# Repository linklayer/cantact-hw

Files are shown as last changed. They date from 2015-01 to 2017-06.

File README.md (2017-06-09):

# CANtact Hardware

This repository contains the hardware design files for the CANtact tool. They 
can be opened and edited with [KiCad](http://www.kicad-pcb.org/).

Documentation can be found on the [Linklayer Wiki](https://wiki.linklayer.com/index.php/CANtact).

A PDF of the schematic is available
[here](https://github.com/CANtact/cantact-hw/blob/master/cantact.pdf?raw=true).

## Official Retailers

- [Linklayer Store](https://store.linklayer.com) (USA)
- [Hacker Warehouse](https://hackerwarehouse.com) (USA)
- [VETEC](http://vctec.co.kr) (South Korea)

## License

Hardware files released under the [Creative Commons Attribution-ShareAlike 4.0
International License](http://creativecommons.org/licenses/by-sa/4.0/) (CC BY-SA
4.0)

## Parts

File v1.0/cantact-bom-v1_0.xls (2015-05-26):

CANtact Bill of Materials |  |  | HW Version: | 1.0
Item | Qty | Reference(s) | Value | MPN | Manufacturer | Package | Digikey P/N
1 | 7 | C1, C11, C13, C16, C2, C4, C6 | 0.1uF | GRM188R71C104KA01D | Murata | 0603 | 490-1532-1-ND
2 | 3 | C10, C14, C15 | 1uF | GRM188R61E105KA12D | Murata | 0603 | 490-3897-1-ND
3 | 3 | C12, C3, C7 | 4.7uF | GRM188R60J475KE19D | Murata | 0603 | 490-3297-1-ND
4 | 2 | C5, C9 | 18pF | CL10C180JB8NNNC | Samsung | 0603 | 1276-1089-1-ND
5 | 1 | C8 | 10nF | GRM188R71H103KA01D | Murata | 0603 | 490-1512-1-ND
6 | 1 | D1 | LED-GREEN | LTST-C191KGKT | Lite-On | 0603 | 160-1446-1-ND
7 | 1 | D2 | LED-RED | LTST-C191KRKT | Lite-On | 0603 | 160-1447-1-ND
9 | 4 | JP2, JP3, JP4, JP5 | 2x2 Header | 15912040 | Molex | 2x2SMD | WM9514-ND
13 | 1 | P1 | USB | USB-B1HSB6 | OST | 4 pin TH | ED2983-ND
15 | 1 | P3 | DB9 | SDS107-PRW1-M09-SN63-11 | Sullins | 9 pin TH | S9575-ND
16 | 1 | R1 | 510 | MCR03ERTF5100 | Rohm | 0603 | RHM510CFCT-ND
17 | 3 | R2, R3, R4 | 120 | MCR03ERTF1200 | Rohm | 0603 | RHM120CFCT-ND
18 | 1 | U1 | STM32F042C6T6 | STM32F042C6T6 | STM | 48 LQFP | 497-14648-ND
19 | 1 | U2 | AAT3221 | AAT3221IGV-3.3-T1 | Skyworks | SOT23-5 | 863-1491-1-ND
20 | 1 | U3 | MCP2561-E/SN | MCP2561-E/SN | Microchip | 8 SOIC | MCP2561-E/SN-ND
21 | 1 | X1 | 16 MHz | 9C-16.000MAAJ-T | TXC | HC49/US | 887-1059-1-ND
22 | 4 | JP2, JP3, J4, JP5 | JUMPER | QPC02SXGN-RC | Sullins | JUMPER | S9337-ND
Total | 36

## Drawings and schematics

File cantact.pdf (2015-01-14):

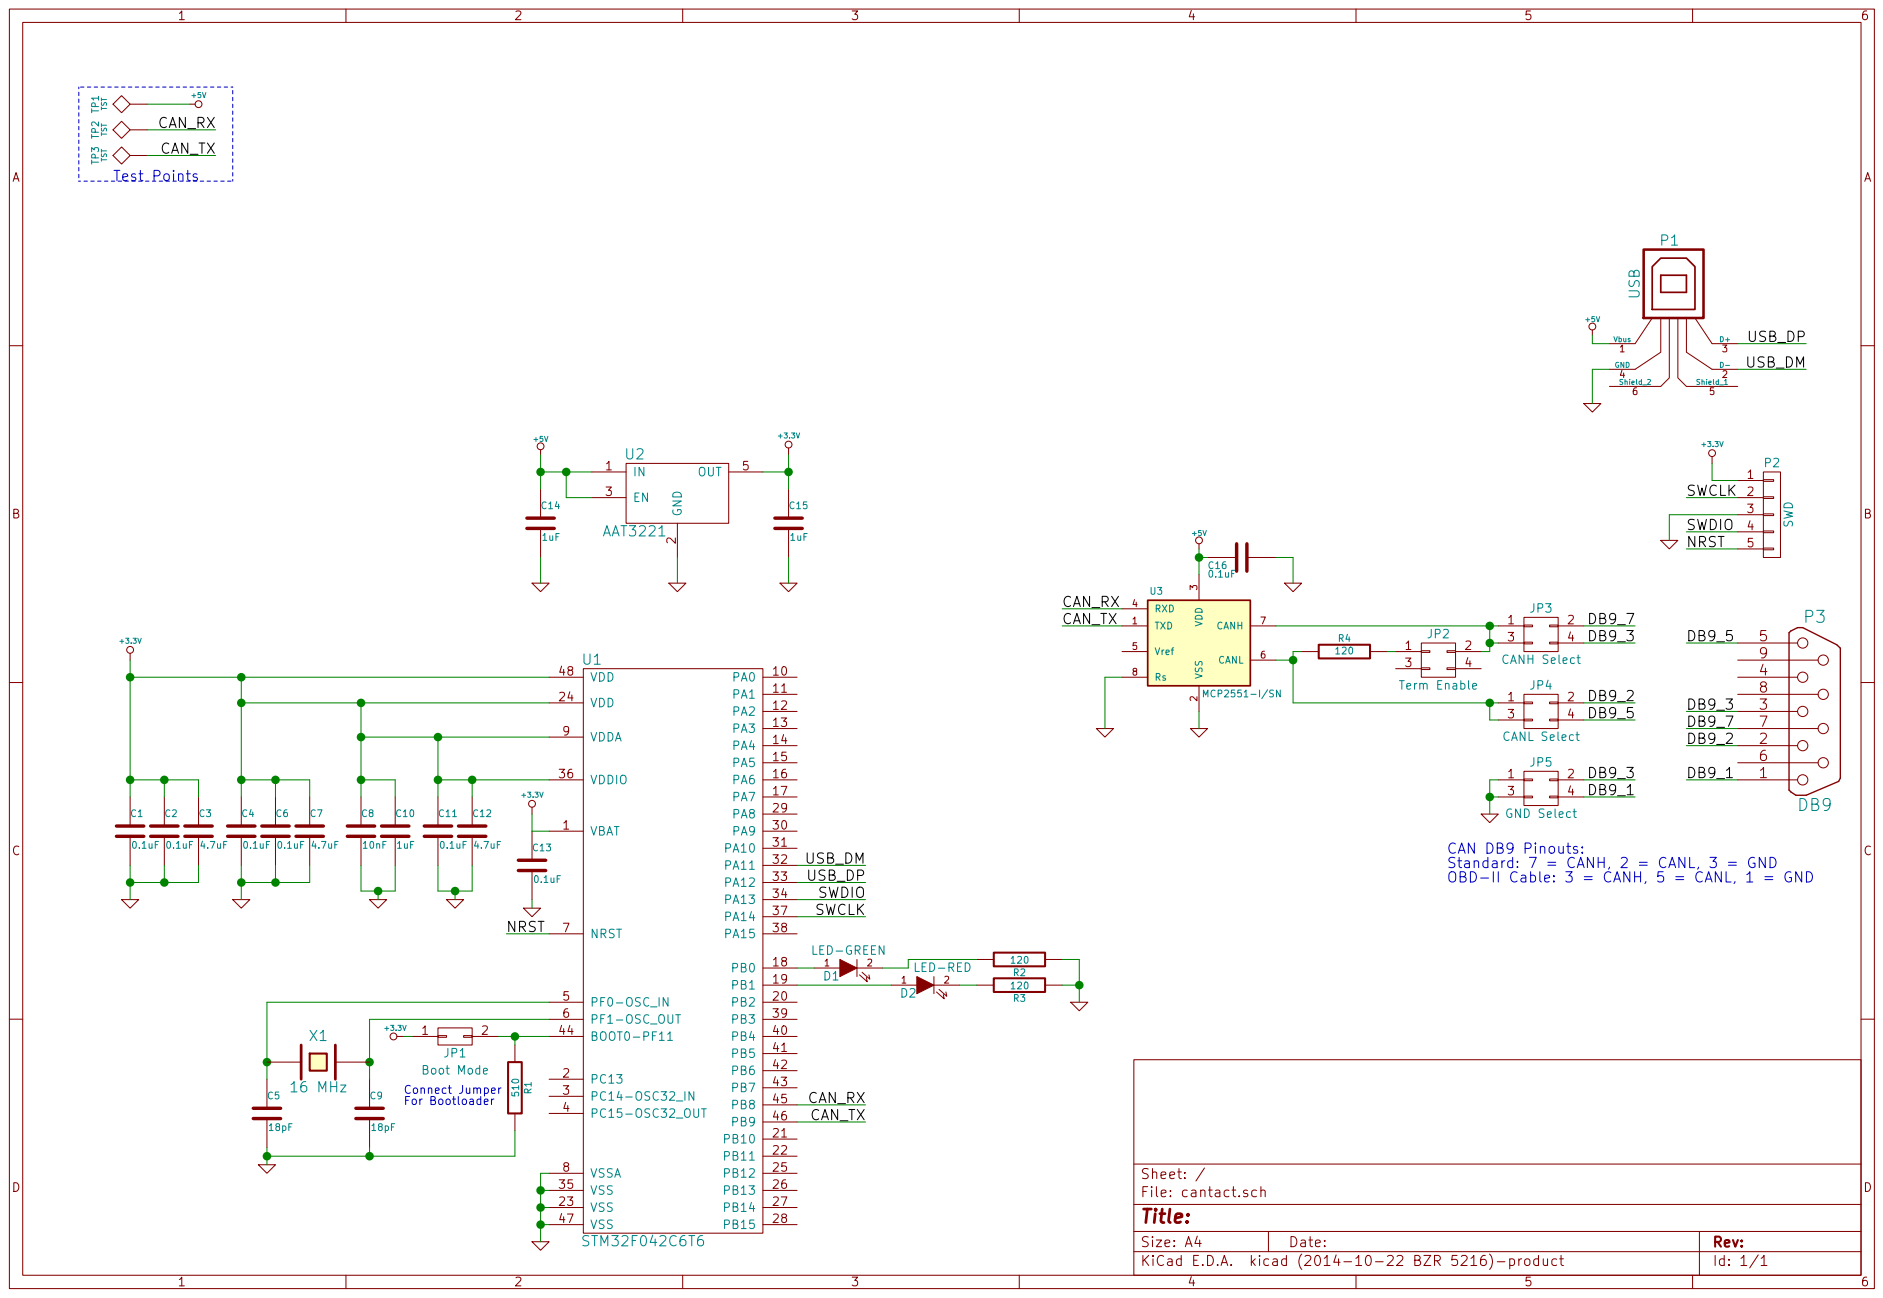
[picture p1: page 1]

3 RXD 4 Vref 5 CANL 6 CANH 7 Rs 8 U3 MCP2551-I/SN CAN_RX
CAN_TX

Id: 1/1 Title: File: cantact.sch Sheet: / C12

Standard: 7 = CANH, 2 = CANL, 3 = GND

OBD-II Cable: 3 = CANH, 5 = CANL, 1 = GND 510 R1

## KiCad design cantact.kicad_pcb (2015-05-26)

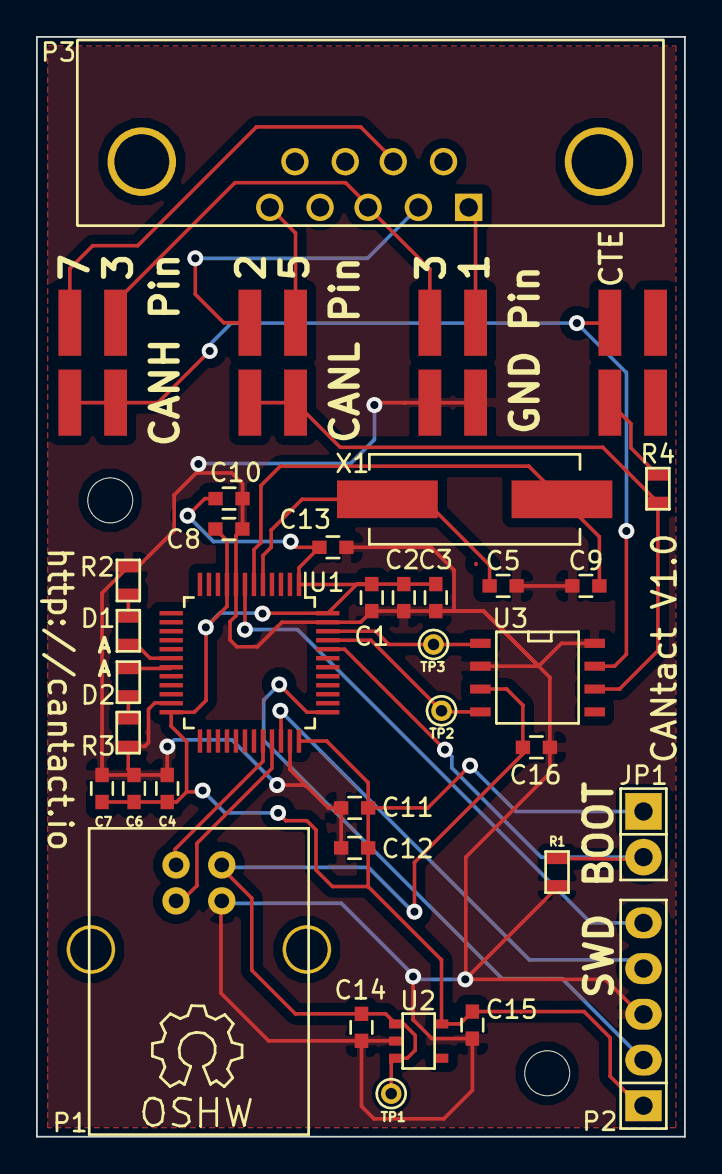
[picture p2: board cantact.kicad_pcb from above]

Board: 2 copper layers, 36.0 x 61.1 mm, 38 parts (0 on the bottom side), 25 nets.

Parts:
C1, C2, C4, C6, C11, C13, C16: 0.1uF; C_0603
C3, C7, C12: 4.7uF; C_0603
C5, C9: 18pF; C_0603
C8: 10nF; C_0603
C10, C14, C15: 1uF; C_0603
D1, D2: LED; SMD-0603
JP1: Boot Mode; Pin_Header_Straight_1x02
JP2: Term Enable; 0015912040
JP3: CANH Select; 0015912040
JP4: CANL Select; 0015912040
JP5: GND Select; 0015912040
P1: USB; USB_B
P2: SWD; Pin_Header_Straight_1x05
P3: DB9; DB9MC
R1: 510; SMD-0603
R2, R3: R; SMD-0603
R4: 120; SMD-0603
SYM: Symbol_OSHW-Logo_SilkScreen_07Jul2012; Symbol_OSHW-Logo_SilkScreen
TP1, TP2, TP3: TST; PINTST
U1: STM32F042C6T6; LQFP-48_7x7mm_Pitch0.5mm
U2: AAT3221; SOT-23-5
U3: MCP2551-I/SN; SOIC-8-N
X1: 16 MHz; Crystal_HC49-SD_SMD

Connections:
+3.3V: C1.1, C2.1, C3.1, C4.1, C6.1, C7.1, C8.1, C10.1, C11.1, C12.1, C13.1, C15.1, JP1.1, P2.1, U1.1, U1.9, U1.24, U1.36, U1.48, U2.5
+5V: C14.1, C16.2, P1.1, TP1.1, U2.1, U2.3, U3.3
/CAN_RX: TP2.1, U1.45, U3.4
/CAN_TX: TP3.1, U1.46, U3.1
/DB9_1: JP5.4, P3.1
/DB9_2: JP4.2, P3.2
/DB9_3: JP3.4, JP5.2, P3.3
/DB9_5: JP4.4, P3.5
/DB9_7: JP3.2, P3.7
/NRST: P2.5, U1.7
/SWCLK: P2.2, U1.37
/SWDIO: P2.4, U1.34
/USB_DM: P1.2, U1.32
/USB_DP: P1.3, U1.33
GND: C1.2, C2.2, C3.2, C4.2, C5.2, C6.2, C7.2, C8.2, C9.2, C10.2, C11.2, C12.2, C13.2, C14.2, C15.2, C16.1, JP5.1, JP5.3, P1.4, P2.3, R1.2, R2.1, R3.1, U1.8, U1.23, U1.35, U1.47, U2.2, U3.2, U3.8
unnamed: C5.1, U1.5, X1.1
unnamed: C9.1, U1.6, X1.2
unnamed: D1.1, U1.18
unnamed: D1.2, R2.2
unnamed: D2.1, U1.19
unnamed: D2.2, R3.2
unnamed: JP1.2, R1.1, U1.44
unnamed: JP2.1, R4.2
unnamed: JP2.2, JP3.1, JP3.3, U3.7
unnamed: JP4.1, JP4.3, R4.1, U3.6

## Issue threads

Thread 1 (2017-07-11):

can I control my car with this tool?

cyberhck, 2017-07-11:
Is this tool only for monitoring or can it also control a car, say steer programmatically, brake and throttle?

crossband, 2017-07-13:
You can not only receive CAN messages, but also send them. It means you could possibly control your vehicle. But it depends on your car.

cyberhck, 2017-07-14:
Hi, thanks for the response. And thanks a lot for the awesome opensource tool (love opensource can't live without them), I'm not yet there (didn't pay attention in my maths class in university), once I go through a little statics, probability and linear algebra, I'll do computer vision and I'll buy this hardware to see if I can hack my car to make a simple lane keeping level 1 vehicle :) thanks. BTW, does this ship worldwide?

crossband, 2017-08-15:
Regarding WW shipment you can ask to Eric. Here is the link to his webspage: http://linklayer.github.io/cantact/

Good luck!

cyberhck, 2018-02-21:
closing this as I did get the info, and there's really no need for this issue to stay open :slightly_smiling_face:

Closed 2018-02-21.

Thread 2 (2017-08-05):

Issues with CANtact on my Mazda

shipcod3, 2017-08-05:
Hello,

I tried the [steps](https://wiki.linklayer.com/index.php/SocketCAN) in my OBD-II connector and here is what I got:

```
root@ubuntu:~# ifconfig
can0      Link encap:UNSPEC  HWaddr 00-00-00-00-00-00-00-00-00-00-00-00-00-00-00-00
          UP RUNNING NOARP  MTU:16  Metric:1
          RX packets:0 errors:0 dropped:0 overruns:0 frame:0
          TX packets:1 errors:0 dropped:0 overruns:0 carrier:0
          collisions:0 txqueuelen:10
          RX bytes:0 (0.0 B)  TX bytes:16 (16.0 B)

ens33     Link encap:Ethernet  HWaddr 00:0c:29:80:d7:24
          inet addr:192.168.96.151  Bcast:192.168.96.255  Mask:255.255.255.0
          inet6 addr: fe80::bb80:92f2:64ef:dc3f/64 Scope:Link
          UP BROADCAST RUNNING MULTICAST  MTU:1500  Metric:1
          RX packets:4954 errors:0 dropped:0 overruns:0 frame:0
          TX packets:3391 errors:0 dropped:0 overruns:0 carrier:0
          collisions:0 txqueuelen:1000
          RX bytes:4238809 (4.2 MB)  TX bytes:286960 (286.9 KB)

lo        Link encap:Local Loopback
          inet addr:127.0.0.1  Mask:255.0.0.0
          inet6 addr: ::1/128 Scope:Host
          UP LOOPBACK RUNNING  MTU:65536  Metric:1
          RX packets:1160 errors:0 dropped:0 overruns:0 frame:0
          TX packets:1160 errors:0 dropped:0 overruns:0 carrier:0
          collisions:0 txqueuelen:1
          RX bytes:170211 (170.2 KB)  TX bytes:170211 (170.2 KB)

root@ubuntu:~# cansend can0 123#1122334455667788
write: No buffer space available
root@ubuntu:~# cansniffer can0

46 delta   ID  data ...                  < cansniffer can0 # l=20 h=100 t=500 >
```

I can't seem to sniff the data on it.

mancoast, 2017-09-25:
have you tried the using native linux installation without vmware?
also, what about using https://github.com/linklayer/cantact-app on windows?
cantact-app is a Java program, try to run it with Java on Windows.

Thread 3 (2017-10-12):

Sporadic problems connecting CANtact to can bus

madsbertelsen, 2017-10-12:
When following [the guide](https://wiki.linklayer.com/index.php/SocketCAN) for connecting using SocketCAN It only works around 50% of the time.

when executing:
` sudo slcand -o -c -s6 /dev/ttyACM0 can0`
(with correct device)
Sometimes the red light (D2) will start blinking and I can subsequently do
`sudo ifconfig can0 up`
and
`cansniffer can0`
and I can see a lot of communication from can bus.

But often the red light never starts blinking and I when that happens I never see can bus communication.

I don't understand what is causing this sporadic behaviour - please help.

inspector71, 2018-05-23:
Completely out of nowhere, and I'm almost certainly not helping, but is the car moving when you're trying to access the data?

I only mention this because the Mazda infotainment systems disallow certain actions when the car's moving. Perhaps that correlates to fifty percent of your experience? Unlikely, I know.

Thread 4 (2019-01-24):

CANtact not being recognized Subaru 2005

fxb6476, 2019-01-24:
I am running a fresh ubuntu install on VMware fusion with my CANtact usb device connected to the virtual machine on /dev/ttyACM0.

The issue is I am running:

sudo slcand -o -c -s6 /dev/ttyACM0 and thing happens, the red light does not turn on. EVER. I just bought my CANtact device today so I am not sure if I have to flash firmware or anything like that...

fxb6476, 2019-01-25:
So it turns out that the Subaru 2005 forester model does not actually have CAN on the OBD II port. :/

Closed 2019-01-25.

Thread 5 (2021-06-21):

STM MCU availability and crazy proces

lsoltero, 2021-06-21:
Hello All

over the last several months we have seen prices of the STM MCU go from about $1.8 to $10 and now our latest purchase at $29.   Has any one looked at the Artery MCU as a possible replacement for STM?  The Artery MCU's look pretty much like a drop-in replacement for many of the STM MCUs.  Wondering if anyone has modified the cantact hw design and candlelight software to run using these?

Artery MCU currently running under $2.

Looking for options.

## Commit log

2015-01-14 initial commit, hardware v0.2
    [cantact.kicad_pcb, cantact.sch]
2015-01-14 hardware v0.3, added mounting holes and text
    [cantact.kicad_pcb]
2015-02-07 added v1.0 draft BOM
2015-02-09 updated BOM and added PDF version
2015-02-09 changed BOM to landscape
2015-05-26 final v1.0 fixes, added assembly files
    [cantact-bom-v1_0.xls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]
2015-05-26 removed pdf bom
